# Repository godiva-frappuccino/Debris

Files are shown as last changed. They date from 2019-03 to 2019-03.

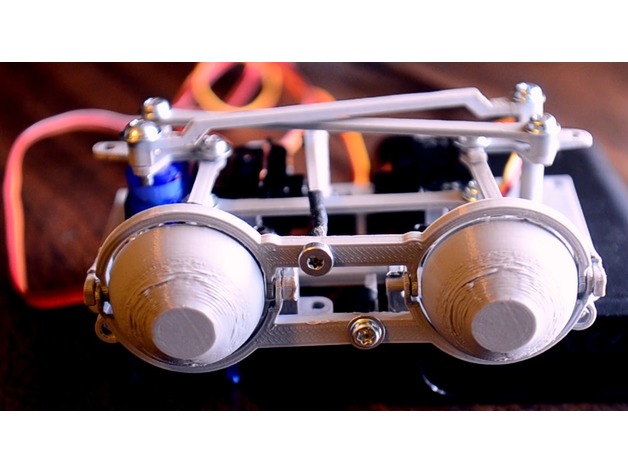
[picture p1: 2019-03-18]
images/a0bb93269ad05ddc474d65502c98058b_preview_featured.jpg

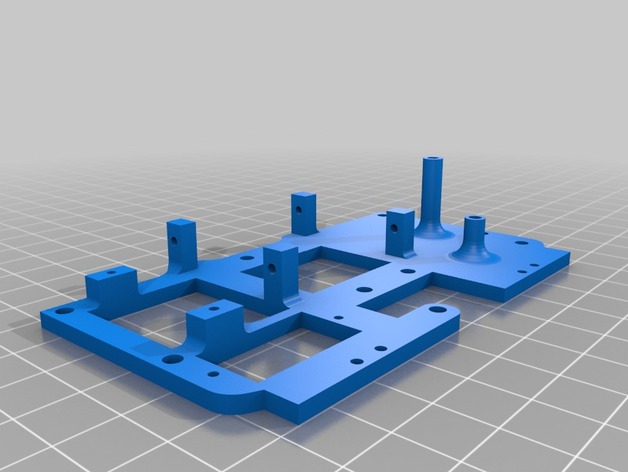
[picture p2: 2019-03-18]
images/0e980e949fc5339d30f437e700b65ad1_preview_featured.jpg

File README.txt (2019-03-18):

                   .:                     :,                                          
,:::::::: ::`      :::                   :::                                          
,:::::::: ::`      :::                   :::                                          
.,,:::,,, ::`.:,   ... .. .:,     .:. ..`... ..`   ..   .:,    .. ::  .::,     .:,`   
   ,::    :::::::  ::, :::::::  `:::::::.,:: :::  ::: .::::::  ::::: ::::::  .::::::  
   ,::    :::::::: ::, :::::::: ::::::::.,:: :::  ::: :::,:::, ::::: ::::::, :::::::: 
   ,::    :::  ::: ::, :::  :::`::.  :::.,::  ::,`::`:::   ::: :::  `::,`   :::   ::: 
   ,::    ::.  ::: ::, ::`  :::.::    ::.,::  :::::: ::::::::: ::`   :::::: ::::::::: 
   ,::    ::.  ::: ::, ::`  :::.::    ::.,::  .::::: ::::::::: ::`    ::::::::::::::: 
   ,::    ::.  ::: ::, ::`  ::: ::: `:::.,::   ::::  :::`  ,,, ::`  .::  :::.::.  ,,, 
   ,::    ::.  ::: ::, ::`  ::: ::::::::.,::   ::::   :::::::` ::`   ::::::: :::::::. 
   ,::    ::.  ::: ::, ::`  :::  :::::::`,::    ::.    :::::`  ::`   ::::::   :::::.  
                                ::,  ,::                               ``             
                                ::::::::                                              
                                 ::::::                                               
                                  `,,`

https://www.thingiverse.com/thing:2951362
Animatronic Eye Mechanism V2 by kinetic-mcf is licensed under the Creative Commons - Attribution license.
http://creativecommons.org/licenses/by/3.0/

# Summary

Video: https://www.youtube.com/watch?v=j3ok9grzXH8

Animatronic eyes using 4 9G servos. Builds from my last design by adding a second eye and eyelids.

How to build it
====================
### You need: 
- 8 M3x5 screws
- 8 M3x7 screws
- 4 micro servos
- Wire (like a paperclip) or 2 small screws
- Shrinkwrap
- Your favorite RC receiver, servo controller, or microcontroller

### Printing:
- Print 2 of eye.stl and eye_mount.stl - you need to mirror one copy left-to-right
- Print 1 of everything else
- Print eye.stl with the flat part on the print bed.
- eye_mount.stl should be printed sideways, with the flat side down, as should eye_top, eye_bottom, eye_top_lever, and eye_bottom_lever. 
- eye_servo_plate should be printed as is. 
- most of the other links should be flipped 180* before printing. 

### Assembly:
Center all your servos, then attach single-sided servo horns to two of them. Depending on the brand, you may need to clip off the last 5mm or so to get them to fit. Then install your servos with their included mounting screws. Use just 1 screw for the two servos that lay on their side since we'll use the other screws for holding on the eye mounts, which can be installed now. Then start assembling the linkages toward the front and work your way back. Use 7mm screws to hold the cross-links onto the servo horns, and 5mm for everything else. Once all the parts are in place, use ~1 cm long strips of shrinkwrap to attach the links to the eyes and eyelids. Shrink them with a soldering iron, just be careful not to destroy the parts themselves!

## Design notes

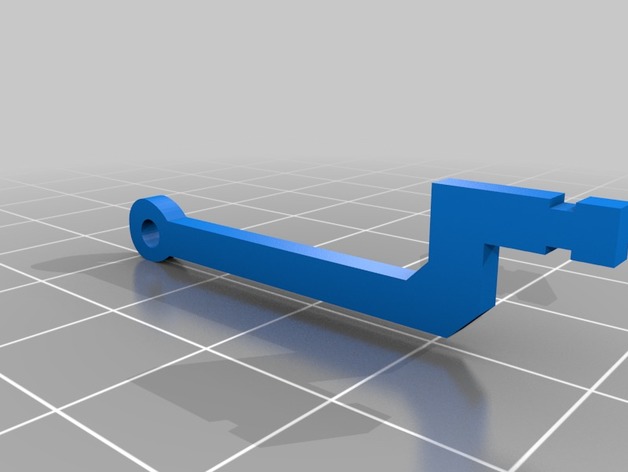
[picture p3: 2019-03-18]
images/cf8e6ab07a8202807476f516ede36142_preview_featured.jpg

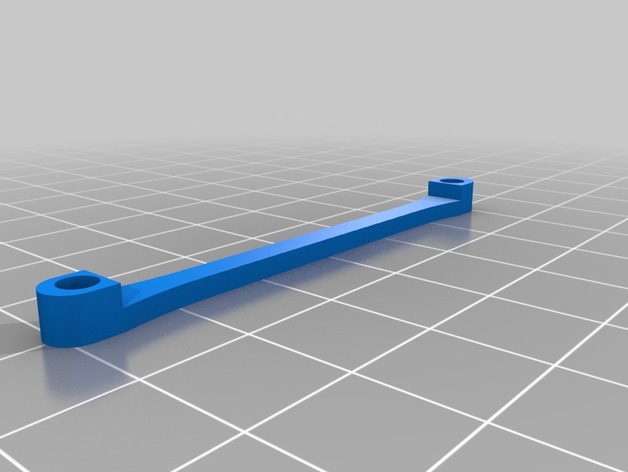
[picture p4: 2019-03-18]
images/fe86e79e791f31e21023d9347fbf52a4_preview_featured.jpg

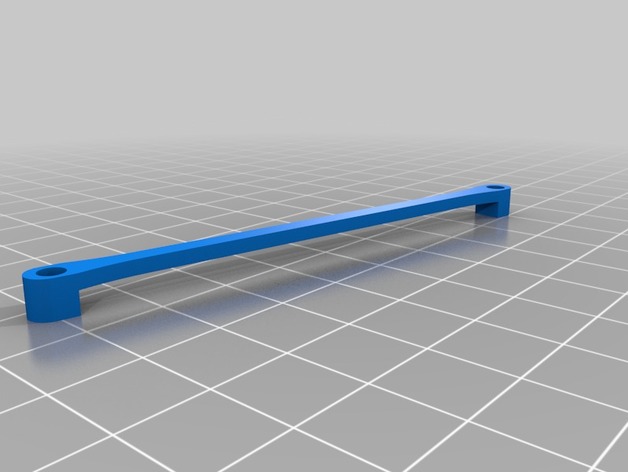
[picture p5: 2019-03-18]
images/d6fe59289ab2a43a55827f3b46332023_preview_featured.jpg

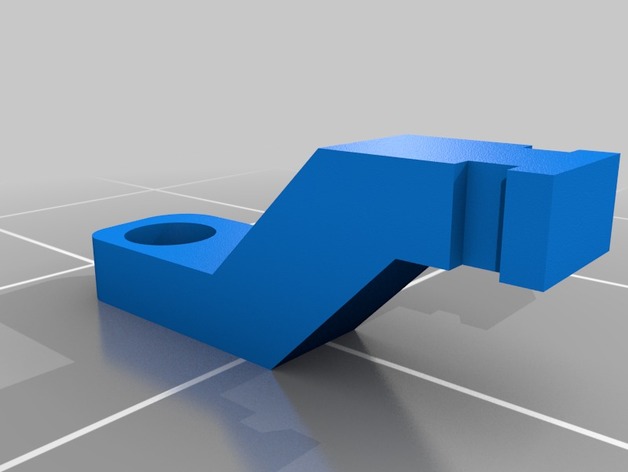
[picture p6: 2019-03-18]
images/c7580ac7876ff4d0bbebbd0f8f9682a1_preview_featured.jpg

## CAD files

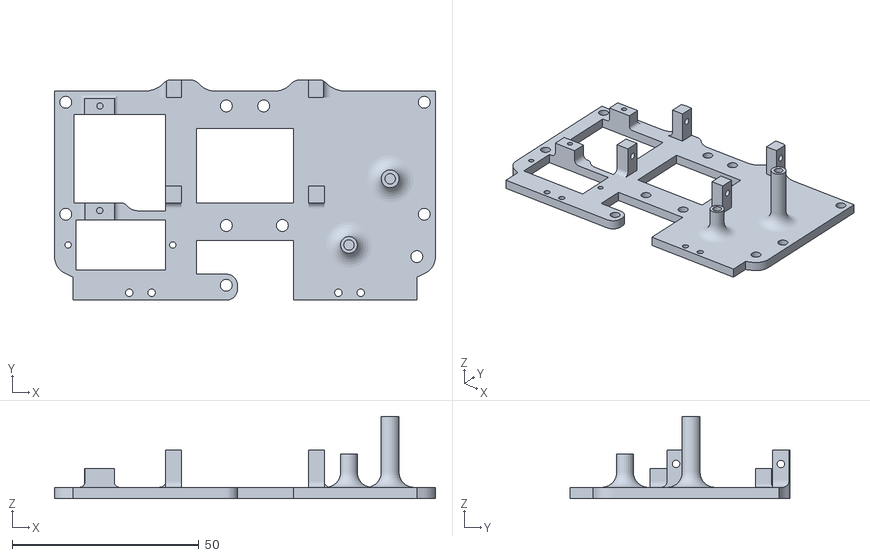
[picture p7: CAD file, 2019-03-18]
files/eye_servo_plate.stl
102.0 x 59.0 x 22.0

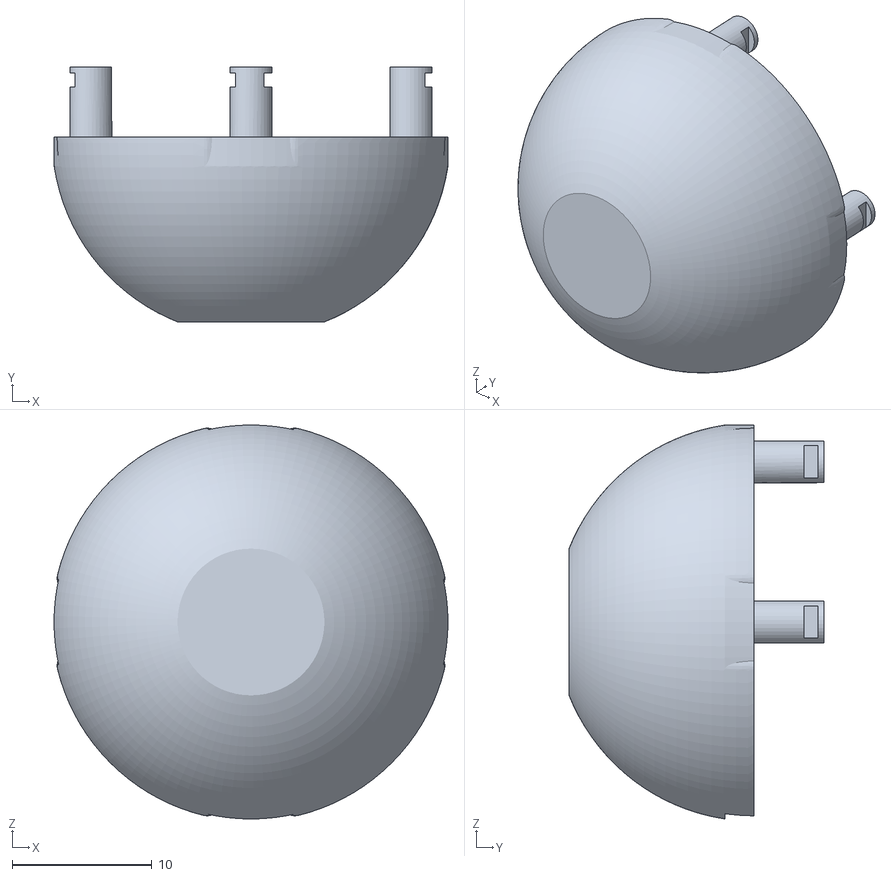
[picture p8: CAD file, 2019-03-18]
files/eye.stl
28.2 x 18.3 x 28.2

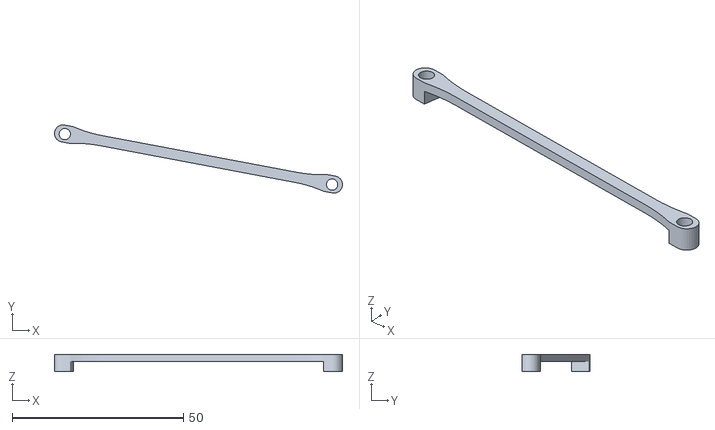
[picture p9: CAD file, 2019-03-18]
files/servo_vt_link_1.stl
84.1 x 19.9 x 5.00

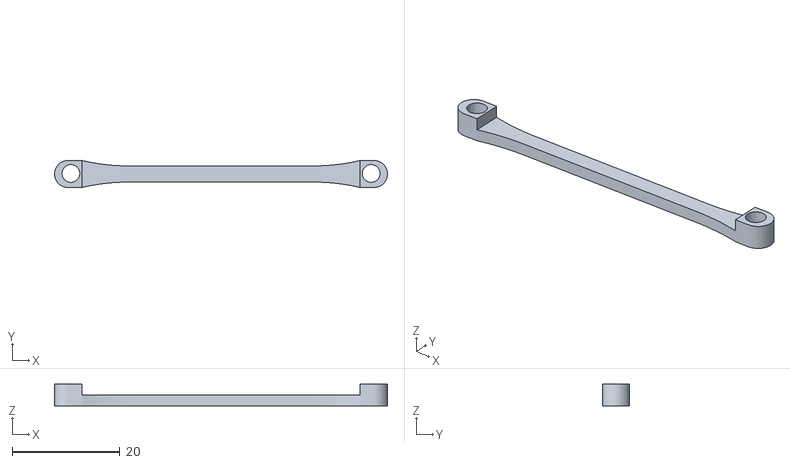
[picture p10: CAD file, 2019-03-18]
files/servo_hz_link.stl
61.7 x 5.00 x 4.00

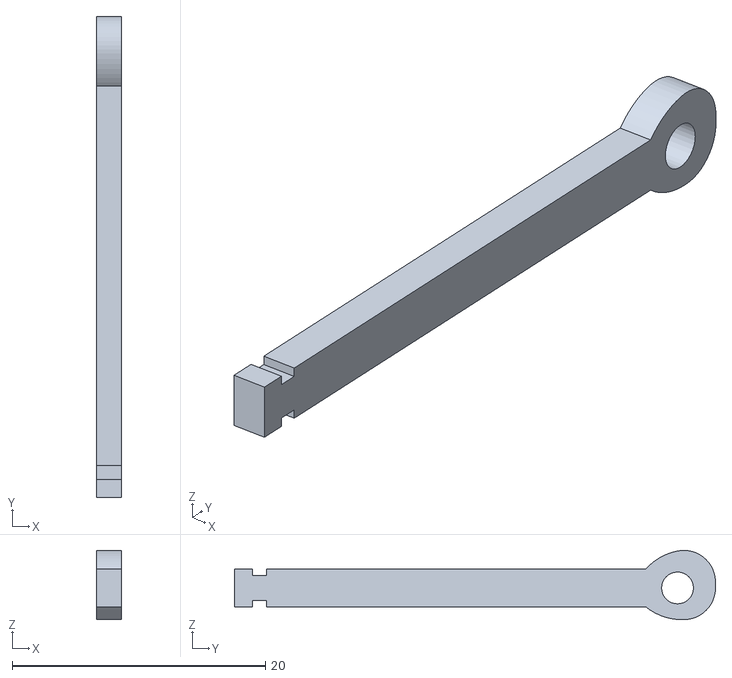
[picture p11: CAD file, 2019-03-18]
files/eye_top_lever.stl
2.00 x 38.0 x 5.47

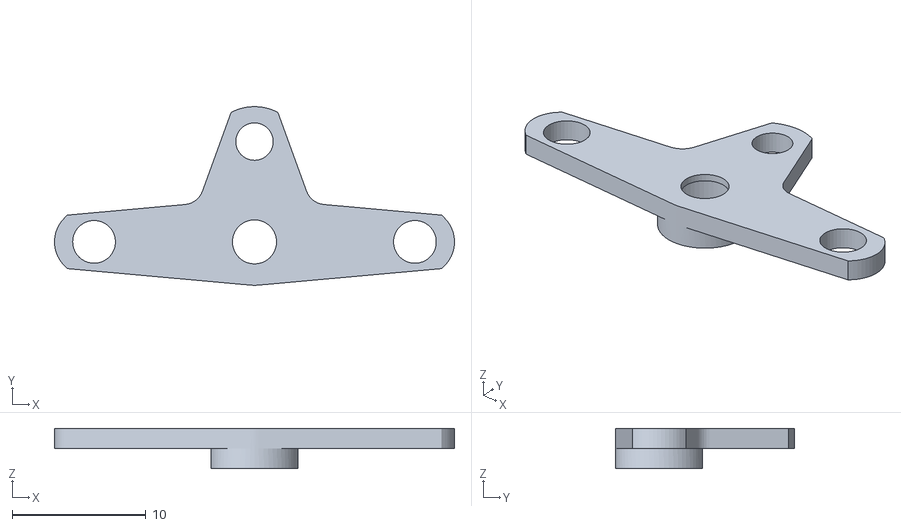
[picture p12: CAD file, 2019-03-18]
files/servo_horn_hz_left.stl
29.9 x 13.4 x 3.00

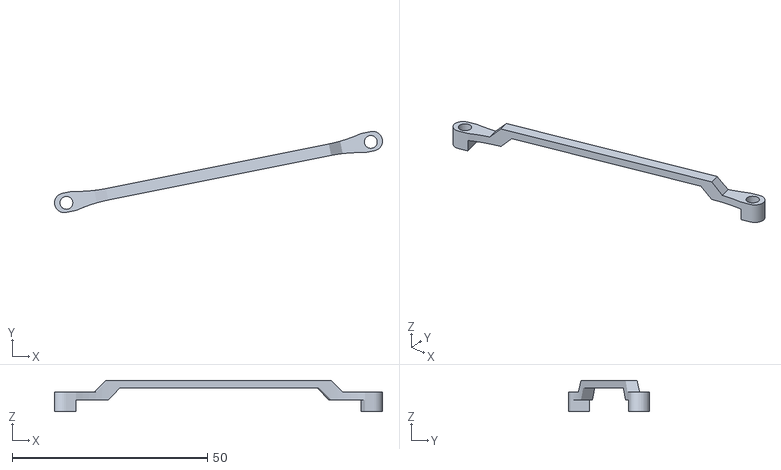
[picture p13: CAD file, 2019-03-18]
files/servo_vt_link_2.stl
83.9 x 20.8 x 8.00

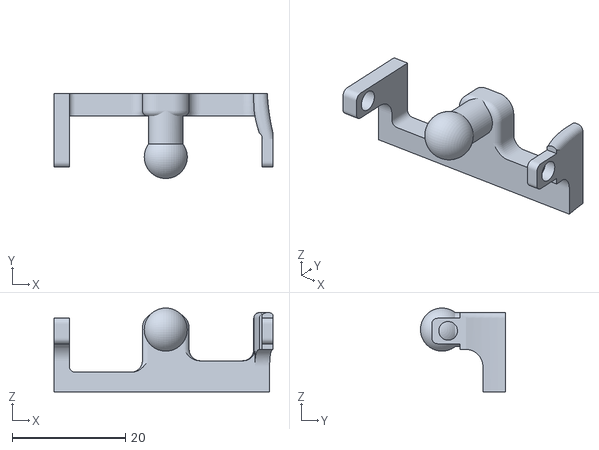
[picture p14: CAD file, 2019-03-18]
files/eye_mount.stl
38.6 x 15.0 x 14.8

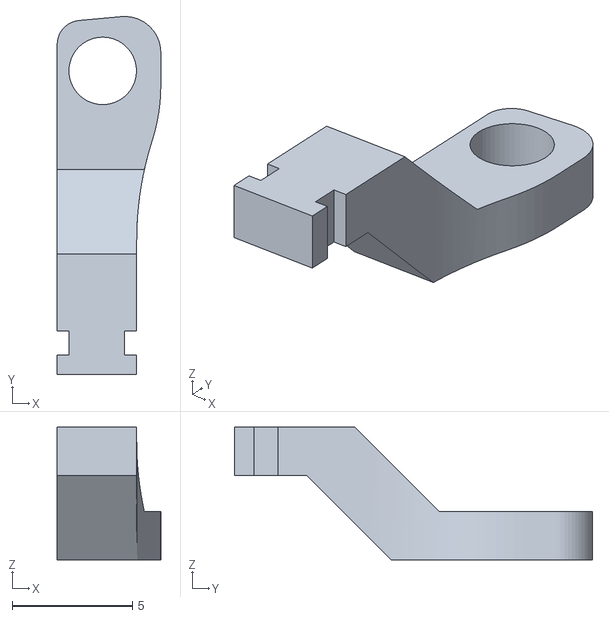
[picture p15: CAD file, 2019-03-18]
files/eye_hz_link_inside.stl
4.30 x 14.9 x 5.50

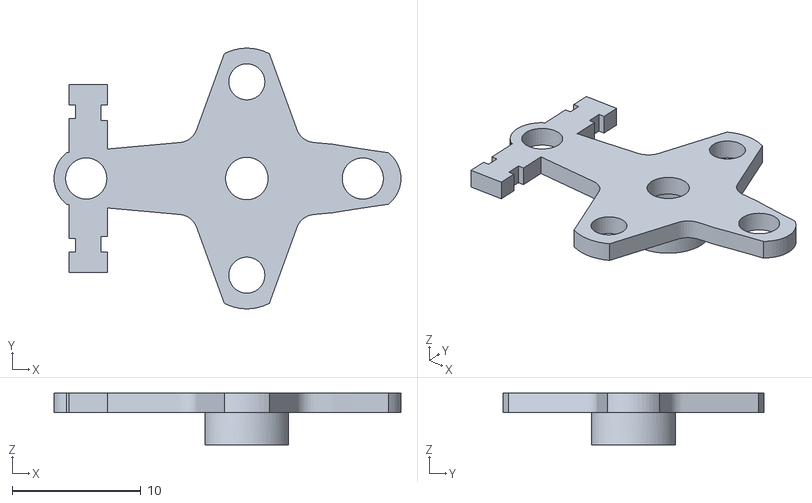
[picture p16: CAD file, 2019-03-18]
files/servo_horn_vt_left.stl
26.9 x 20.2 x 4.00

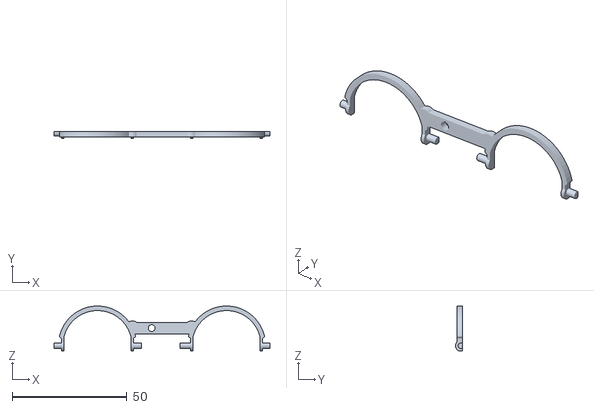
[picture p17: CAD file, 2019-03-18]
files/eye_top.stl
94.1 x 3.11 x 19.6

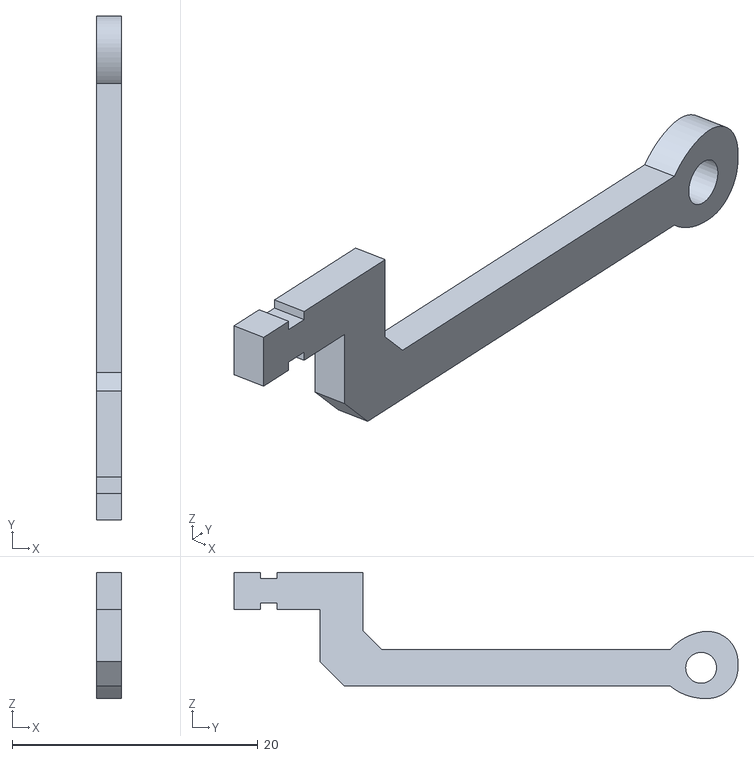
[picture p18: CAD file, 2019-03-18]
files/eye_bottom_lever.stl
2.00 x 41.0 x 10.3

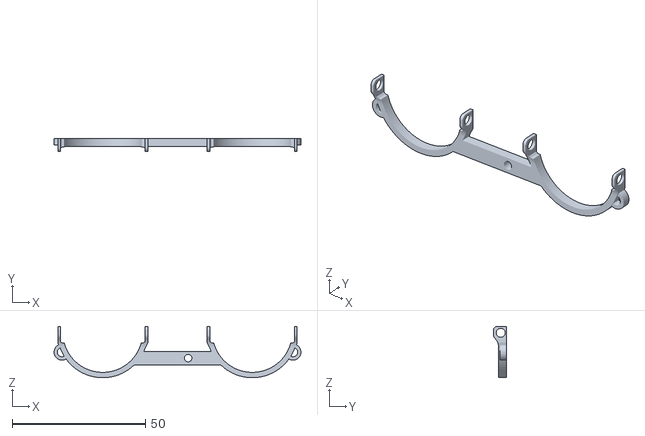
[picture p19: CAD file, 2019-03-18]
files/eye_bottom.stl
92.8 x 5.00 x 19.3

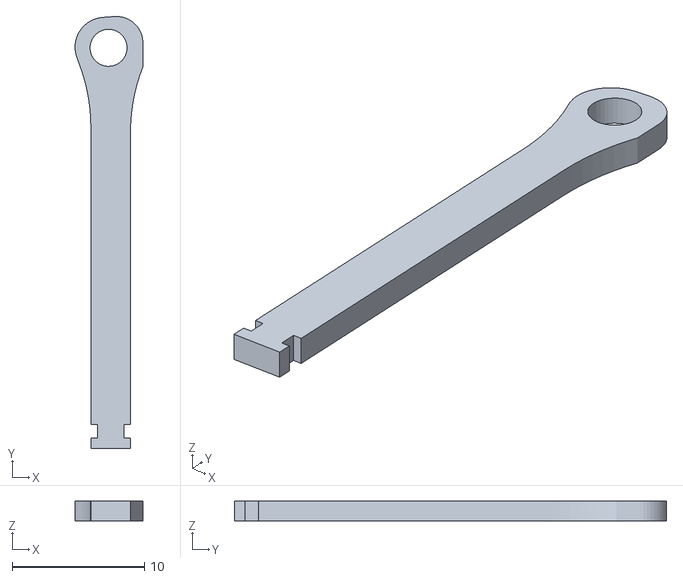
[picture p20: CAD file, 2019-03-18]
files/eye_vt_link_left.stl
5.14 x 32.7 x 1.50

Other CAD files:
files/eye_hz_link_outside.stl
files/servo_horn_hz.stl
files/eye_vt_link.stl

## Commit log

2019-03-18 add stl
2019-03-18 add all files
    [eye.stl, eye_bottom.stl, eye_bottom_lever.stl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]
